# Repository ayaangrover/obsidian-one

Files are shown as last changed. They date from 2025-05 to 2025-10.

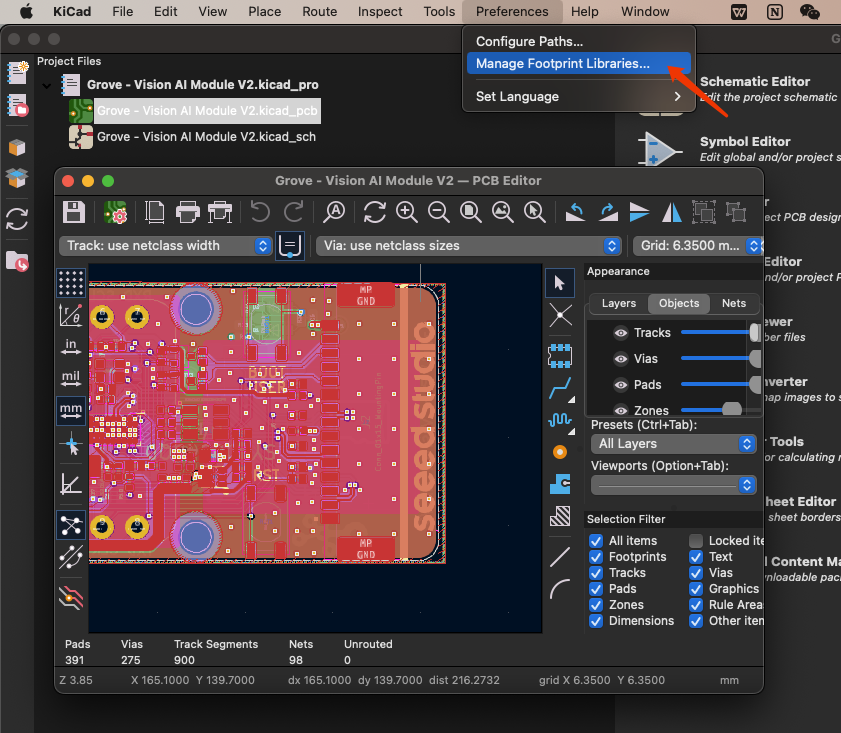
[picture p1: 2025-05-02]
pcb/OPL_Kicad_Library-master/images/4.png

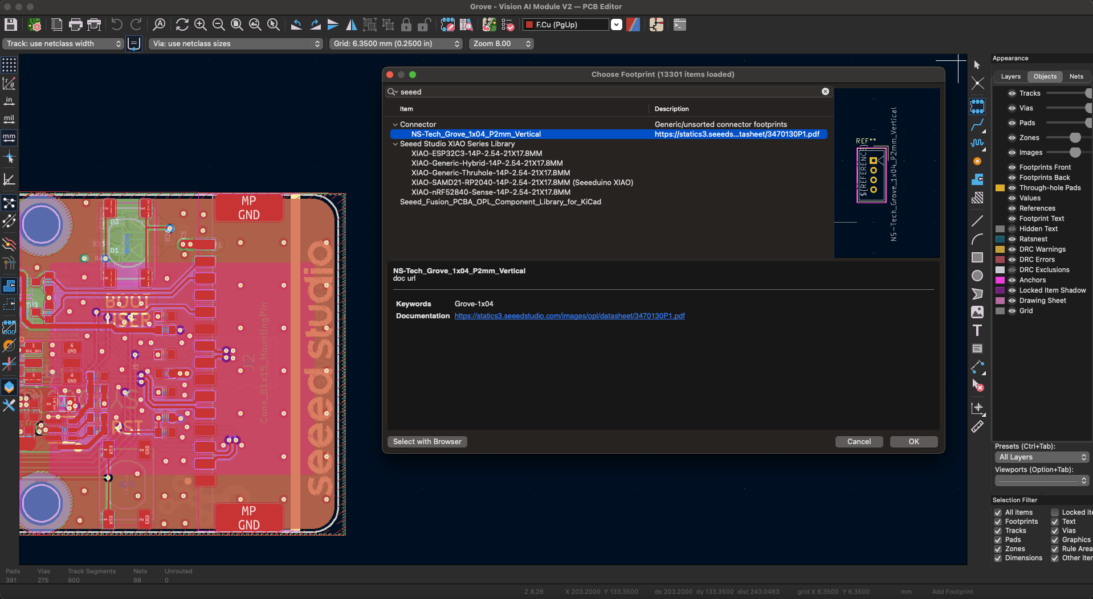
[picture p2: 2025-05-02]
pcb/OPL_Kicad_Library-master/images/19.png

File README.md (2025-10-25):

# Obsidian One: a 75% hotswappable mechanical keyboard

## Overview

The PCB uses MX-style switches with PCB mounting and hotswap. The MCU(microcontroller - the device that tells the computer whenever you press a key) is a basic [Pi Pico RP2040/RP2350](https://www.canakit.com/raspberry-pi-pico.html).

## Why I made it

My current keyboard(Keychron K6 from #pyramid-scheme) has no function key row, and requires an uncomfortable combo to pause music. To fix this, I made Obsidian One which has the extra row.

## PCB

The PCB is in the /keyboard folder. Inside is the production folder, which includes the gerber file.

## Firmware

### KMK

In the /firmware/kmk folder, you'll find a CIRCUITPY folder showing exactly what your MCU should look like when you plug it in. First, flash micropython. You can find instructions on how to do that [here](https://www.raspberrypi.com/documentation/microcontrollers/micropython.html). Then, eject, unplug, and reconnect the MCU. Once you're done, it should appear as a usb drive named CIRCUITPY. Now, replace the contents of the drive/mcu with the items in the /firmware/kmk/CIRCUITPY directory. Upon restarting(unplugging + reconnecting) the MCU, it should be functioning properly.

NOTE: This KMK firmware hasn't been tested. Flashing it to your microcontroller may cause damage or render it incapable of function. Use it at your own risk.

### QMK

The QMK firmware was made with QMK Configurator. It made a .hex file and I used microsoft's uf2conv.py and uf2families.json to convert it to a .uf2 file, which can be flashed to the MCU. You can see it at /firmware/qmk.

NOTE: This QMK firmware hasn't been tested. Flashing it to your microcontroller may cause damage or render it incapable of function. Use it at your own risk.

## Case

The case is available at ./case

## BOM

| Quantity | Item | Notes/Details | Source |
|---|---|---|---|
| 84x | Kailh Hotswap Sockets | | https://www.aliexpress.us/item/3256804104247622.html?gatewayAdapt=glo2usa |
| 84x | MX-compatible switches | MMD Princess Tactile 48gs | Amazon - https://www.amazon.com/KPREPUBLIC-Princess-Tactile-Mechanical-Keyboard/dp/B0C533FYXJ?sr=8-1 |
| 84x | Compatible keycaps | | [Amazon](https://www.amazon.com/dagaladoo-keycaps-Topographic-Percent-Keyboard/dp/B0CH2KSD7J?sr=8-68&xpid=GHBM-RxRzepH2) |
| 84x | 1N4148 THT Diodes | | https://www.aliexpress.us/item/2255800939822415.html?gatewayAdapt=glo2usa |
| 2x 2u, 1x 6.25u | Stabilizers | Cherry-style | [CannonKeys](https://cannonkeys.com/products/cherry-stabilizers?variant=32257338998895) |
| 1x | Orpheus Pico | Controller board | Hack Club HQ |
| 1x | Case | 3D-printed or purchased enclosure | JLCPCB/#printing-legion |
| 1x | PCB | Custom-designed for this project | JLCPCB |

### Extra stuff for the BOM:

- Solder

- Soldering Iron

- Flux as needed

## Pictures: 

CleanShot 2025-06-04 at 22 17 38

CleanShot 2025-05-09 at 12 09 41@2x

CleanShot 2025-05-09 at 12 36 32@2x

CleanShot 2025-05-09 at 12 40 01@2x

CleanShot 2025-10-25 at 07 35 13@2x

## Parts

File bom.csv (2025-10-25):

Quantity | Item | Notes/Details | Source
84x | Kailh Hotswap Sockets |  | https://www.aliexpress.us/item/3256804104247622.html?gatewayAdapt=glo2usa
84x | MX-compatible switches | MMD Princess Tactile 48gs | https://www.amazon.com/KPREPUBLIC-Princess-Tactile-Mechanical-Keyboard/dp/B0C533FYXJ?sr=8-1
84x | Compatible keycaps |  | https://www.amazon.com/Keycaps-Keyboard-Profile-Switches-Mechanical/dp/B0B4JV49DG?sr=8-22
84x | 1N4148 THT Diodes |  | https://www.aliexpress.us/item/2255800939822415.html?gatewayAdapt=glo2usa
2x 2u/1x 6.25u | Stabilizers |  | https://cannonkeys.com/products/cherry-stabilizers?variant=32257338998895
1x | Orpheus Pico / Pi Pico if Orpheus Pi isn't available | Preferrably an orph pico for usb c | Hack Club HQ
1x | Case |  | JLCPCB/#printing-legion
1x | PCB |  | JLCPCB

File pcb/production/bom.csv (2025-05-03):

Designator | Footprint | Quantity | Value | LCSC Part #
A1 | RaspberryPi_Pico_Common_THT | 1 | RaspberryPi_Pico
D1, D10, D11, D12, D13, D14, D15, D16, D17, D18, D19, D2, D20, D21, D22, D23, D24, D25, D26, D27, D28, D29, D3, D30, D31, D32, D33, D34, D35, D36, D37, D38, D39, D4, D40, D41, D42, D43, D44, D45, D46, D47, D48, D49, D5, D50, D51, D52, D53, D54, D55, D56, D57, D58, D59, D6, D60, D61, D62, D63, D64, D65, D66, D67, D68, D69, D7, D70, D71, D72, D73, D74, D75, D76, D77, D8, D82, D83, D84, D85, D86, D87, D88, D9 | Diode_DO-35 | 84 | Diode
S1, S10, S11, S12, S13, S14, S15, S16, S17, S18, S19, S2, S20, S21, S22, S23, S24, S25, S26, S27, S28, S29, S3, S32, S33, S34, S35, S36, S37, S38, S39, S4, S40, S41, S42, S43, S44, S46, S48, S49, S5, S50, S51, S52, S53, S54, S55, S56, S57, S58, S6, S61, S62, S63, S64, S65, S66, S67, S68, S69, S7, S70, S71, S73, S74, S8, S83, S84, S85, S86, S87, S88, S9 | Hotswap_MX_1.00u | 73 | Keyswitch
S30 | Hotswap_MX_2.00u | 1 | Keyswitch
S31, S45 | Hotswap_MX_1.50u | 2 | Keyswitch
S47, S72 | Hotswap_MX_1.75u | 2 | Keyswitch
S59, S60 | Hotswap_MX_2.25u | 2 | Keyswitch
S75, S76, S77 | Hotswap_MX_1.25u | 3 | Keyswitch
S82 | Hotswap_MX_6.25u | 1 | Keyswitch

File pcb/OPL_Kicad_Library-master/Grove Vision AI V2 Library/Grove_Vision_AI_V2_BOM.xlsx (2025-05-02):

Layer Jump | Number | Name | Specification | Operating Temperature | MPN Code | Quantity | Base | Plug Position | Process
N | 301010000 | SMD RES 0R-5%-1/16W;0402 |  | -55°C to 155°C | RC0402JR-070RL | 3 | 1 | R29,R30,R39 | SMT1
N | 301010004 | SMD RES 10K-5%-1/16W;0402 |  | -55°C to 155°C | RC0402JR-0710KL | 7 | 1 | R5,R7,R8,R23,R24,R31,R38 | SMT1
N | 301010008 | SMD RES 510K-5%-1/16W;0402 |  | -55°C to 155°C | RC0402JR-07510KL | 1 | 1 | R35 | SMT1
N | 301010456 | SMD RES 100K-1%-1/16W;0402 |  | -55°C to 155°C | RC0402FR-07100KL | 7 | 1 | R6,R10,R11,R16,R32,R33,R37 | SMT1
N | 301010495 | SMD RES;5.1K-1%-1/16W;0402 |  | -55°C to 155°C | RC0402FR-075K1L | 3 | 1 | R2,R3,R36 | SMT1
N | 301010746 | SMD RES 2.2K-1%-1/16W;0402 |  | -55°C to 155°C | RC0402FR-072K2L | 10 | 1 | R1,R4,R13,R14,R15,R19,R20,R21,R22,R40 | SMT1
N | 301011331 | SMD RES 22.1K-1%-1/16W;0402 |  | -55°C to 155°C | RC0402FR-0722K1L | 2 | 1 | R26,R34 | SMT1
N | 302010004 | SMD CAP Ceramic 100nF-16V-10%-X7R;0402 |  | -55°C to 125°C | CC0402KRX7R7BB104 | 18 | 1 | C5,C8,C13,C20,C21,C22,C23,C24,C25,C26,C27,C29,C30,C31,C32,C35,C36,C39 | SMT1
N | 302010006 | SMD CAP Ceramic 10nF-50V-10%-X7R;0402 |  | -55°C to 125°C | CC0402KRX7R9BB103 | 1 | 1 | C3 | SMT1
N | 302010049 | SMD CAP Ceramic 12pF-50V-5%-NPO;0402 |  | -55°C to 125°C | CC0402JRNPO9BN120 | 2 | 1 | C14,C15 | SMT1
N | 302010051 | SMD CAP Ceramic 220nF-16V-10%-X7R;0402 |  | -55°C to 125°C | CC0402KRX7R7BB224 | 1 | 1 | C16 | SMT1
N | 302010407 | SMD CAP Ceramic 4.7uF-10V-10%-X5R;0402 |  | -55°C to 85°C | CC0402KRX5R6BB475 | 7 | 1 | C4,C6,C7,C9,C10,C28,C34 | SMT1
N | 302010519 | SMD CAP Ceramic 10uF-10V-20%-X5R;0402 |  | -55°C to 85°C | CC0402MRX5R6BB106 | 2 | 1 | C11,C37 | SMT1
N | 302013249 | SMD CAP Ceramic 1uF-10V-10%-X5R;0402 |  | -55°C to 85°C | CL05A105KP5NNNC | 5 | 1 | C1,C2,C17,C18,C19 | SMT1
N | 303010544 | SMD Inductor 4.7uH-20%-1.1A;0806 |  | -40°C to 105°C | VLS201610HBX-4R7M-1 | 1 | 1 | L1 | SMT1
N | 303011858 | SMD Inductor 470nH-20%-2.6A;0603 |  | -40°C to 125°C | TFM160808ALC-R47MTAA | 2 | 1 | L2,L3 | SMT1
N | 304011053 | SMD Diode Schottky 40V-1A;SOD-323 |  |  | B5819WS SL | 4 | 1 | D1,D2,D3,D4 | SMT1
N | 304090121 | SMD LED Clear-Green;0402 | As posted |  | BL-HGE37A-AV-TRB | 1 | 1 | LED2 | SMT1
N | 304090746 | SMD LED Clear-Yellow;0402 | As posted |  | 16-213/Y2C-AN2Q1B/3T | 1 | 1 | LED1 | SMT1
N | 305030071 | SMD MOSFET N-CH 20V-500mA;SOT-523 |  |  | CJ1012 | 5 | 1 | Q1,Q2,Q3,Q4,Q5 | SMT1
N | 306011444 | SMD Crystal;24MHz-12pF-10ppm-4P-2.0*1.6*0.5mm |  | -40°C to 85°C | Y2400FE001 | 1 | 1 | X1 | SMT1
N | 310011697 | SMD IC MCU;Dual Cortex-M55 Core(Max 400MHz)-With a 400MHz NPU;WLCSP-65 | L5.58*W2.27mm | -40°C to 85°C | HX6538-A01TWA | 1 | 1 | U1 | SMT1
N | 310032794 | SMD IC PMIC;DCDC Buck-ADJ-2.2MHz-4A;DFN1.5×1.5-6 |  | -40°C to 85°C | SY80004DQD | 2 | 1 | U4,U6 | SMT1
N | 310032813 | SMD IC PMIC;LDO-1.8V-300mA;XTDFN-1*1-4L |  | -40°C to 125°C | SGM2036S-1.8XXDH4G/TR | 1 | 1 | U3 | SMT1
N | 310071431 | SMD IC Interface USB to High Speed TTL;QFN16 | USB to High-Speed Serial Port | -40°C to 85°C | CH343P | 1 | 1 | U2 | SMT1
N | 310091468 | SMD IC Memory;128Mbit-1.8V;SOIC-8 |  | -40°C to 85°C | W25Q128JWSIQ | 1 | 1 | U5 | SMT1
N | 311020009 | SMD Top Button 4N;4P-L4.6*W3.2*H2.5mm |  | -20°C to 70°C | SKRPADE010 | 1 | 1 | RST1 | SMT1
N | 311020518 | SMD Top Button 1.57N;4P-L4.6*W3.2*H2.5mm |  | -30°C to 85°C | SKRPABE010 | 1 | 1 | BOOT1 | SMT1
N | 312030502 | SMD DIGITAL MIC OMNI -26dBFS;OCLGA-4:3.5*2.65*0.94mm |  | -40˚C to 100˚C | MSM261D3526H1CPM | 1 | 1 | MIC1 | SMT1
N | 319015667 | PCB;Grove - Vision AI Module V2 -蓝油白字-4层 | 20*40*1.6mm-ENIG-FR4;Steel mesh code；404012305 |  |  | 1 | 1 |  | SMT1
N | 320011358 | SMD USB TYPE C-W/P;12+4P-8.94*7.35*3.26mm |  | -30°C to 85°C | USB-31C-F-16P-L7.35 | 1 | 1 | J1 | SMT1
N | 320031231 | DIP Black Female Header VERT;1*7P-2.54-5.0mm |  | -40℃ to 105℃ |  | 2 | 1 | P8,P9 | Unit
N | 320060904 | SMD FPC CONN Bottom Contact;15P-1.0mm;L19.9*W6.76*H2.0mm |  | -30°C to 85°C | ST-FPC-W102015-D | 1 | 1 | J2 | SMT1
N | 320090535 | SMD uSD Card Holder;9+4P-L11.25*W6.96*H1.42mm |  | -25°C to 70°C | ST-TF-MR267 | 1 | 1 | J5 | SMT1
N | 320110032 | SMD Grove Female Header-Beige;4P-2.0-90D | 2.0-4PHorizontal Mount with Locking Socket |  | PHS-4A horizontal mount | 1 | 1 | J3 | SMT1

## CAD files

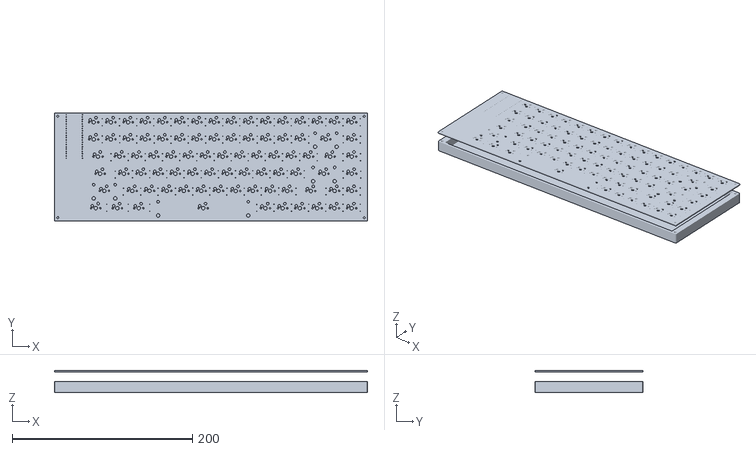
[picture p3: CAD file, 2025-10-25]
case/full.stl
347.0 x 119.7 x 24.5

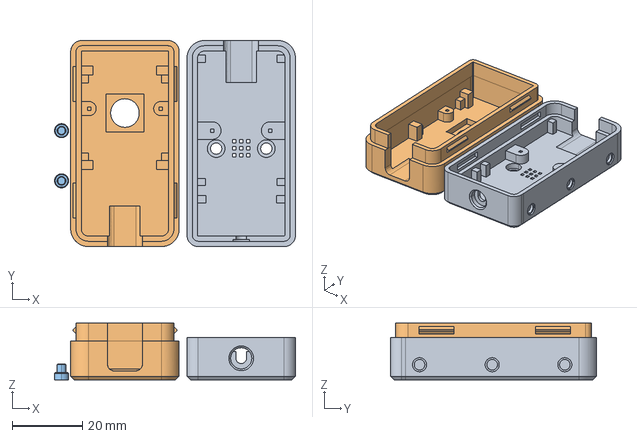
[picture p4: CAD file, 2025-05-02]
pcb/OPL_Kicad_Library-master/Grove Vision AI V2 Library/himax.stp
68.4 x 58.5 x 16.1 mm

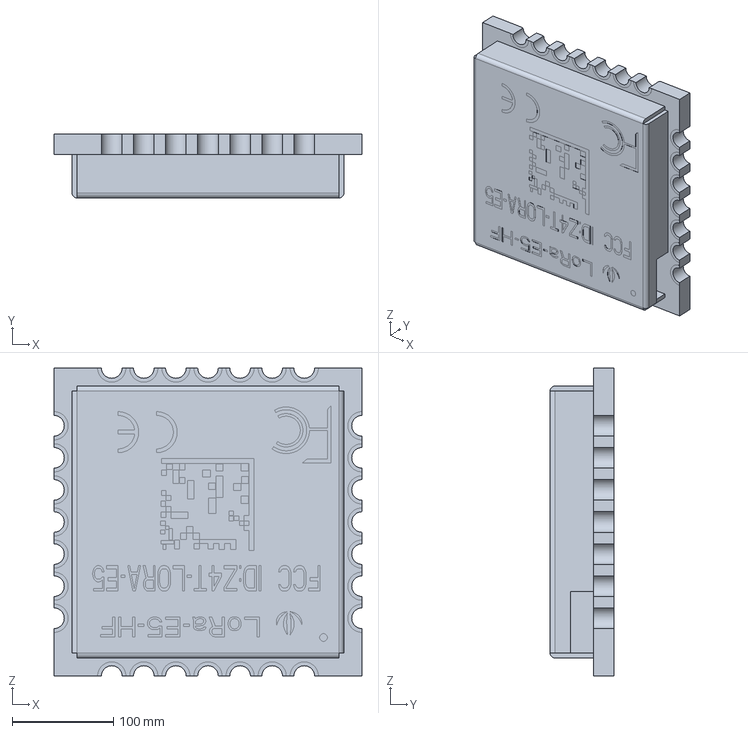
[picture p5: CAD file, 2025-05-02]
pcb/OPL_Kicad_Library-master/Seeed Studio Wio Series/Wio-E5-LE/LoRa-E5-LE-HF_3D_File.stp
304.8 x 63.8 x 304.8 mm

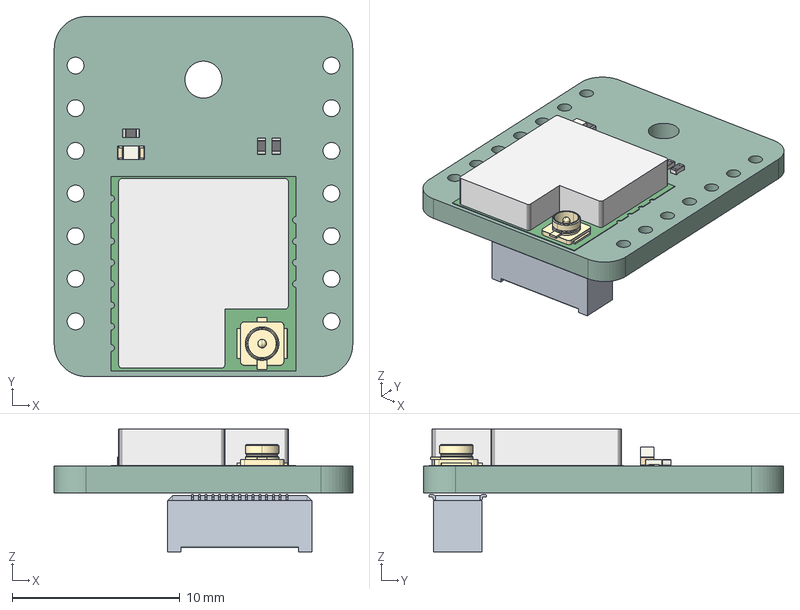
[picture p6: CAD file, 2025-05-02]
pcb/OPL_Kicad_Library-master/Seeed Studio Wio Series/Wio-SX1262/Wio-SX1262_for_XIAO_3D_file.step
17.8 x 21.4 x 7.30 mm
R_0402_1005Metric x 3
LED_0603_1608Metric
PCB
BF04-30pin-35H
Wio-SX1262 for XIAO V1.0_PCB

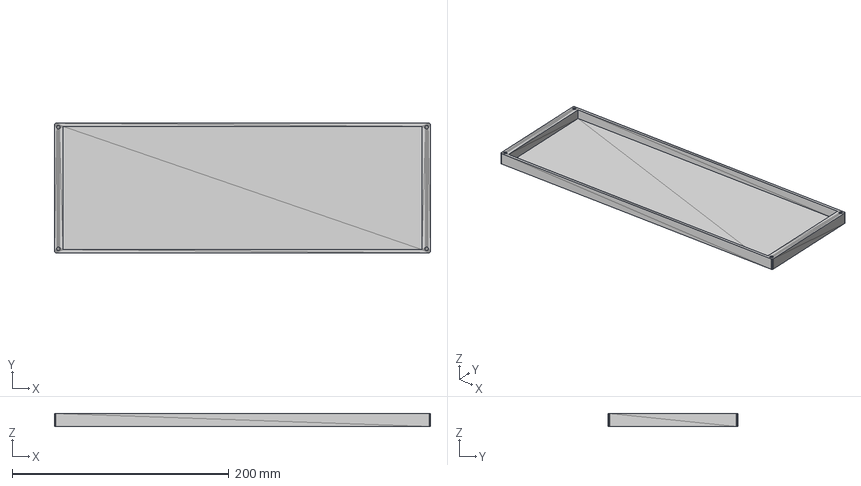
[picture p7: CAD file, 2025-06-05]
case/case.step
347.0 x 119.7 x 12.0 mm

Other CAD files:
case/case.stl
pcb/OPL_Kicad_Library-master/Grove Vision AI V2 Library/himax.3mf

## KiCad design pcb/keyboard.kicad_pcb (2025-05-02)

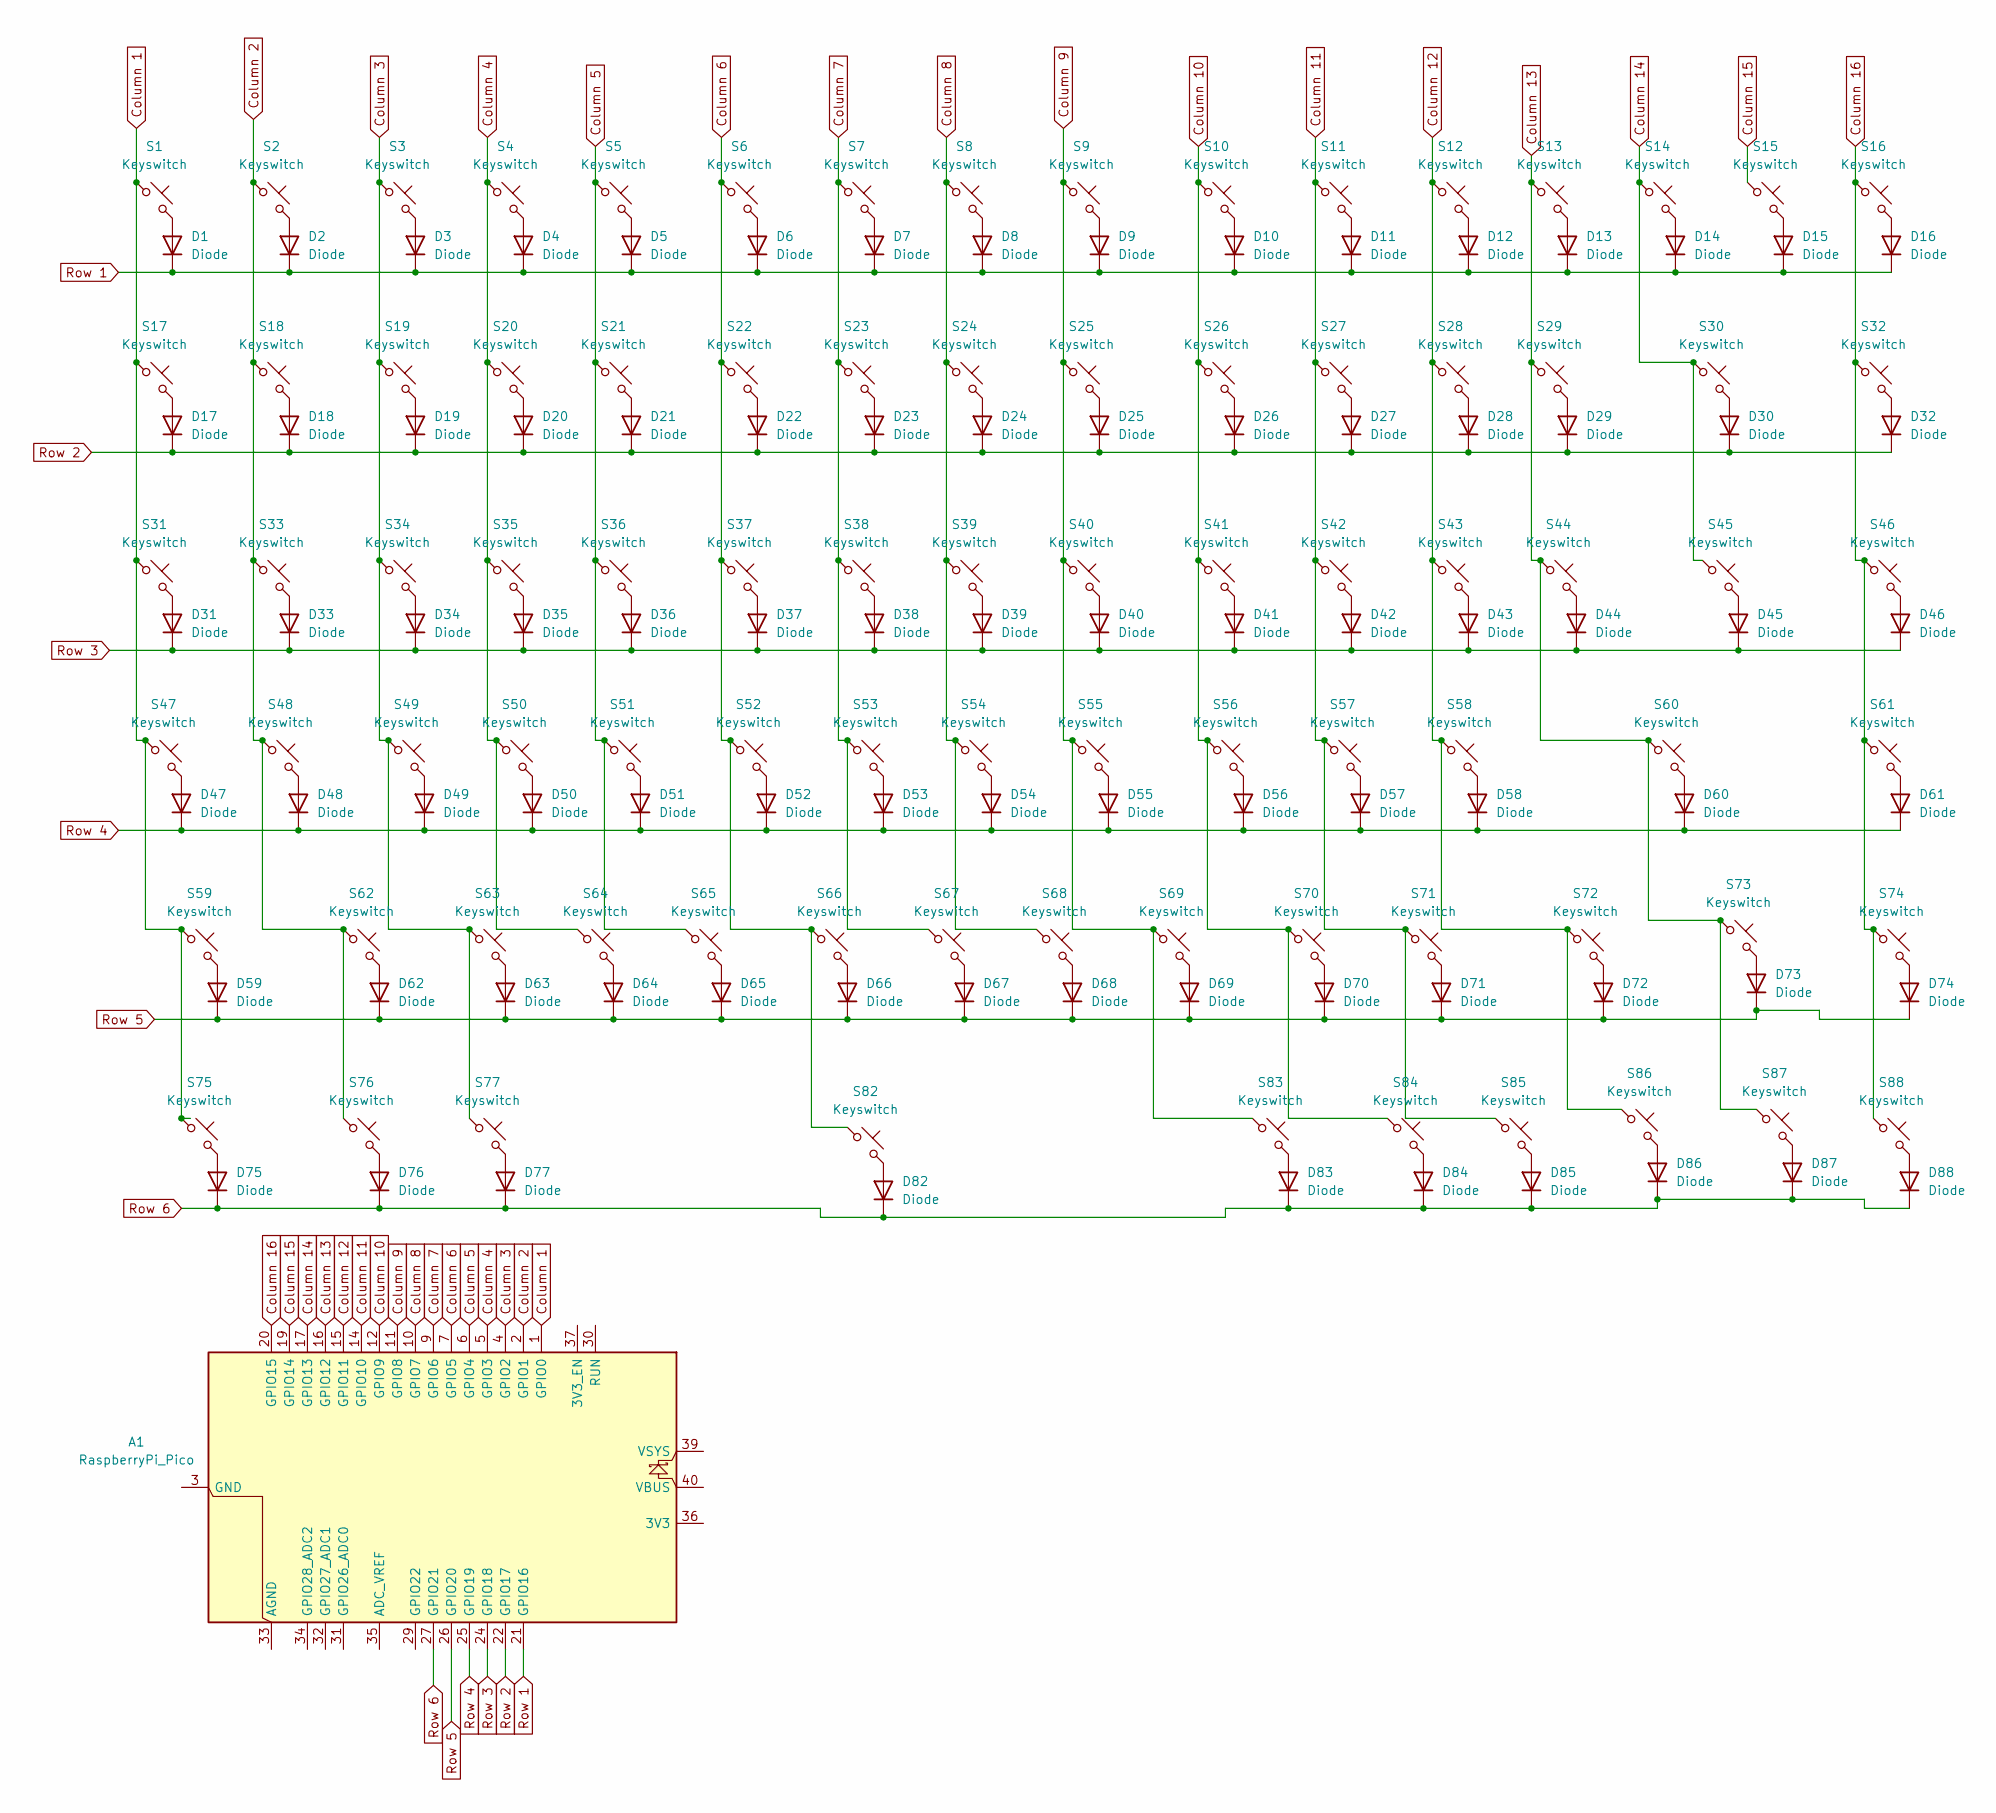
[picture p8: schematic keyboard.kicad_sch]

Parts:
A1: RaspberryPi_Pico; RaspberryPi_Pico_Common_THT
D1, D2, D3, D4, D5, D6, D7, D8, D9, D10, D11, D12, D13, D14, D15, D16, D17, D18, D19, D20, D21, D22, D23, D24, D25, D26, D27, D28, D29, D30, D31, D32, D33, D34, D35, D36, D37, D38, D39, D40, D41, D42, D43, D44, D45, D46, D47, D48, D49, D50, D51, D52, D53, D54, D55, D56, D57, D58, D59, D60, D61, D62, D63, D64, D65, D66, D67, D68, D69, D70, D71, D72, D73, D74, D75, D76, D77, D82, D83, D84, D85, D86, D87, D88: Diode; Diode_DO-35
S1, S2, S3, S4, S5, S6, S7, S8, S9, S10, S11, S12, S13, S14, S15, S16, S17, S18, S19, S20, S21, S22, S23, S24, S25, S26, S27, S28, S29, S32, S33, S34, S35, S36, S37, S38, S39, S40, S41, S42, S43, S44, S46, S48, S49, S50, S51, S52, S53, S54, S55, S56, S57, S58, S61, S62, S63, S64, S65, S66, S67, S68, S69, S70, S71, S73, S74, S83, S84, S85, S86, S87, S88: Keyswitch; Hotswap_MX_1.00u
S30: Keyswitch; Hotswap_MX_2.00u
S31, S45: Keyswitch; Hotswap_MX_1.50u
S47, S72: Keyswitch; Hotswap_MX_1.75u
S59, S60: Keyswitch; Hotswap_MX_2.25u
S75, S76, S77: Keyswitch; Hotswap_MX_1.25u
S82: Keyswitch; Hotswap_MX_6.25u

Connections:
Column 1: A1.1 (GPIO0), S1.1, S17.1, S31.1, S47.1, S59.1, S75.1
Column 2: A1.2 (GPIO1), S2.1, S18.1, S33.1, S48.1, S62.1, S76.1
Column 3: A1.4 (GPIO2), S3.1, S19.1, S34.1, S49.1, S63.1, S77.1
Column 4: A1.5 (GPIO3), S4.1, S20.1, S35.1, S50.1, S64.1
Column 5: A1.6 (GPIO4), S5.1, S21.1, S36.1, S51.1, S65.1
Column 6: A1.7 (GPIO5), S6.1, S22.1, S37.1, S52.1, S66.1, S82.1
Column 7: A1.9 (GPIO6), S7.1, S23.1, S38.1, S53.1, S67.1
Column 8: A1.10 (GPIO7), S8.1, S24.1, S39.1, S54.1, S68.1
Column 9: A1.11 (GPIO8), S9.1, S25.1, S40.1, S55.1, S69.1, S83.1
Column 10: A1.12 (GPIO9), S10.1, S26.1, S41.1, S56.1, S70.1, S84.1
Column 11: A1.14 (GPIO10), S11.1, S27.1, S42.1, S57.1, S71.1, S85.1
Column 12: A1.15 (GPIO11), S12.1, S28.1, S43.1, S58.1, S72.1, S86.1
Column 13: A1.16 (GPIO12), S13.1, S29.1, S44.1, S60.1, S73.1, S87.1
Column 14: A1.17 (GPIO13), S14.1, S30.1, S45.1
Column 15: A1.19 (GPIO14), S15.1
Column 16: A1.20 (GPIO15), S16.1, S32.1, S46.1, S61.1, S74.1, S88.1
unnamed: A1.3 (GND), A1.8 (GND), A1.13 (GND), A1.18 (GND), A1.23 (GND), A1.28 (GND), A1.38 (GND)
unnamed: D1.2 (A), S1.2
unnamed: D2.2 (A), S2.2
unnamed: D3.2 (A), S3.2
unnamed: D4.2 (A), S4.2
unnamed: D5.2 (A), S5.2
unnamed: D6.2 (A), S6.2
unnamed: D7.2 (A), S7.2
unnamed: D8.2 (A), S8.2
unnamed: D9.2 (A), S9.2
unnamed: D10.2 (A), S10.2
unnamed: D11.2 (A), S11.2
unnamed: D12.2 (A), S12.2
unnamed: D13.2 (A), S13.2
unnamed: D14.2 (A), S14.2
unnamed: D15.2 (A), S15.2
unnamed: D16.2 (A), S16.2
unnamed: D17.2 (A), S17.2
unnamed: D18.2 (A), S18.2
unnamed: D19.2 (A), S19.2
unnamed: D20.2 (A), S20.2
unnamed: D21.2 (A), S21.2
unnamed: D22.2 (A), S22.2
unnamed: D23.2 (A), S23.2
unnamed: D24.2 (A), S24.2
unnamed: D25.2 (A), S25.2
unnamed: D26.2 (A), S26.2
unnamed: D27.2 (A), S27.2
unnamed: D28.2 (A), S28.2
unnamed: D29.2 (A), S29.2
unnamed: D30.2 (A), S30.2
unnamed: D31.2 (A), S31.2
unnamed: D32.2 (A), S32.2
unnamed: D33.2 (A), S33.2
unnamed: D34.2 (A), S34.2
unnamed: D35.2 (A), S35.2
unnamed: D36.2 (A), S36.2
unnamed: D37.2 (A), S37.2
unnamed: D38.2 (A), S38.2
unnamed: D39.2 (A), S39.2
unnamed: D40.2 (A), S40.2
unnamed: D41.2 (A), S41.2
unnamed: D42.2 (A), S42.2
unnamed: D43.2 (A), S43.2
unnamed: D44.2 (A), S44.2
unnamed: D45.2 (A), S45.2
unnamed: D46.2 (A), S46.2
unnamed: D47.2 (A), S47.2
unnamed: D48.2 (A), S48.2
unnamed: D49.2 (A), S49.2
unnamed: D50.2 (A), S50.2
unnamed: D51.2 (A), S51.2
unnamed: D52.2 (A), S52.2
unnamed: D53.2 (A), S53.2
unnamed: D54.2 (A), S54.2
unnamed: D55.2 (A), S55.2
unnamed: D56.2 (A), S56.2
unnamed: D57.2 (A), S57.2
unnamed: D58.2 (A), S58.2
unnamed: D59.2 (A), S59.2
unnamed: D60.2 (A), S60.2
unnamed: D61.2 (A), S61.2
unnamed: D62.2 (A), S62.2
unnamed: D63.2 (A), S63.2
unnamed: D64.2 (A), S64.2
unnamed: D65.2 (A), S65.2
unnamed: D66.2 (A), S66.2
unnamed: D67.2 (A), S67.2
unnamed: D68.2 (A), S68.2
unnamed: D69.2 (A), S69.2
unnamed: D70.2 (A), S70.2
unnamed: D71.2 (A), S71.2
unnamed: D72.2 (A), S72.2
unnamed: D73.2 (A), S73.2
unnamed: D74.2 (A), S74.2
unnamed: D75.2 (A), S75.2
unnamed: D76.2 (A), S76.2
unnamed: D77.2 (A), S77.2
unnamed: D82.2 (A), S82.2
unnamed: D83.2 (A), S83.2
unnamed: D84.2 (A), S84.2
unnamed: D85.2 (A), S85.2
unnamed: D86.2 (A), S86.2
unnamed: D87.2 (A), S87.2
unnamed: D88.2 (A), S88.2
Row 1: A1.21 (GPIO16), D1.1 (K), D2.1 (K), D3.1 (K), D4.1 (K), D5.1 (K), D6.1 (K), D7.1 (K), D8.1 (K), D9.1 (K), D10.1 (K), D11.1 (K), D12.1 (K), D13.1 (K), D14.1 (K), D15.1 (K), D16.1 (K)
Row 2: A1.22 (GPIO17), D17.1 (K), D18.1 (K), D19.1 (K), D20.1 (K), D21.1 (K), D22.1 (K), D23.1 (K), D24.1 (K), D25.1 (K), D26.1 (K), D27.1 (K), D28.1 (K), D29.1 (K), D30.1 (K), D32.1 (K)
Row 3: A1.24 (GPIO18), D31.1 (K), D33.1 (K), D34.1 (K), D35.1 (K), D36.1 (K), D37.1 (K), D38.1 (K), D39.1 (K), D40.1 (K), D41.1 (K), D42.1 (K), D43.1 (K), D44.1 (K), D45.1 (K), D46.1 (K)
Row 4: A1.25 (GPIO19), D47.1 (K), D48.1 (K), D49.1 (K), D50.1 (K), D51.1 (K), D52.1 (K), D53.1 (K), D54.1 (K), D55.1 (K), D56.1 (K), D57.1 (K), D58.1 (K), D60.1 (K), D61.1 (K)
Row 5: A1.26 (GPIO20), D59.1 (K), D62.1 (K), D63.1 (K), D64.1 (K), D65.1 (K), D66.1 (K), D67.1 (K), D68.1 (K), D69.1 (K), D70.1 (K), D71.1 (K), D72.1 (K), D73.1 (K), D74.1 (K)
Row 6: A1.27 (GPIO21), D75.1 (K), D76.1 (K), D77.1 (K), D82.1 (K), D83.1 (K), D84.1 (K), D85.1 (K), D86.1 (K), D87.1 (K), D88.1 (K)

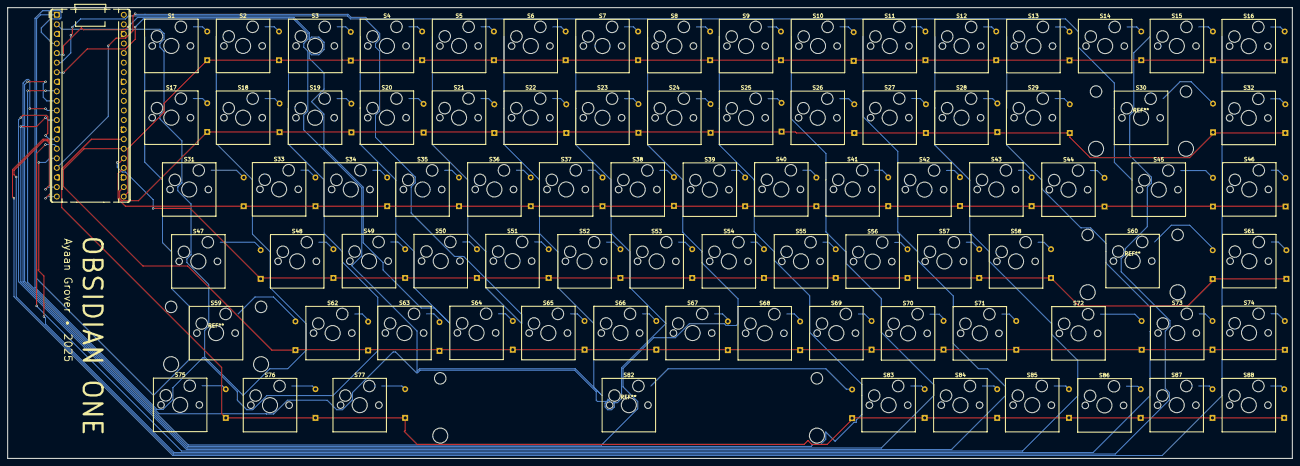
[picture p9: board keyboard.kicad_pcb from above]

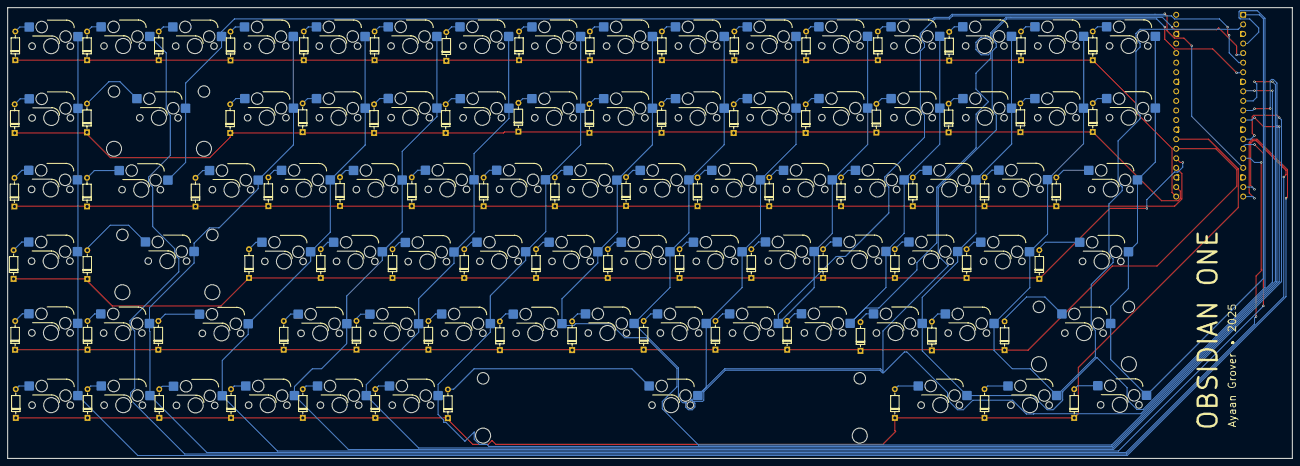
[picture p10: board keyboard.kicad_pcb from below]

Board: 2 copper layers, 341.1 x 119.7 mm, 169 parts (84 on the bottom side), 107 nets.

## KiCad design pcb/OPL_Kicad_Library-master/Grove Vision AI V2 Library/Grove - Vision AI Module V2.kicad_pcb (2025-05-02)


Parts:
BOOT1: SW_Push; SW_Push_1P1T_NO_Vertical_Wuerth_434133025816
C1, C2, C17, C18, C19: 1uF; C0402
C3: 10nF; C0402
C4, C6, C7, C9, C10, C28, C34: 4.7uF; C0402
C5, C8, C13, C20, C21, C22, C23, C24, C25, C26, C27, C29, C30, C31, C32, C35, C36, C39: 100nF; C0402
C11, C37: 10uF; C0402
C14, C15: 12pF; C0402
C16: 220nF; C0402
D1, D2, D3, D4: B5819WS; D0805_SOD323
D5, D6, D7, D8: DNP; R0402; MPN DF2S6.8FS
J1: USB_C_Receptacle_USB2.0; USB2.0-TYPE-C
J2: Conn_01x15_MountingPin; FPC_DNC_15P_1.0mm
J3: Conn_01x04_MountingPin; 4P-SMD-2.0mm-RIGHT
J5: ST-TF-MR267; SD-TF-MR267; MPN SD-TF-MR267
L1: VLS201610HBX-4R7M-1; L0806
L2, L3: 470nH; L0603
LED1: Yellow; LED0402
LED2: Green; LED0402
M1: XIAO Connector/DNP; XIAO_Socket
MIC1: MSM261D3526H1CPM; MIC6P-3.5X2.65X0.94MM
Q1, Q2, Q3, Q4, Q5: CJ1012; SOT523
R1, R4, R13, R14, R15, R19, R20, R21, R22, R40: 2.2k; R0402
R2, R3, R36: 5.1k; R0402
R5, R7, R23, R24: 10k; R0402
R6, R16, R32, R33: 100K; R0402; Power Rating 1%; MPN RC0402JR-074K7L
R8, R31, R38: 10K; R0402; Power Rating 5%; MPN RC0402JR-074K7L
R9, R12, R17, R18, R25, R27, R28: DNP; R0402
R10, R11, R37: 100k; R0402
R26, R34: 22K; R0402; Power Rating 1%; MPN RC0402JR-074K7L
R29, R30, R39: 0R; R0402
R35: 510k; R0402
RST1: SW_Push; SW_Push_1P1T_NO_Vertical_Wuerth_434133025816
TP1, TP2, TP3: Test Point; TP-D35MIL; Part Type Test Point
U1: HX6538; WLCSP65_5.6x2.3x0.56mm
U2: CH343P; QFN-16-EP_3x3mm_P0.5mm_EP1x1mm
U3: WR0331-18FF4R; X2SON-4
U4, U6: SY80004DQD; DFN6-0.5-1.5X1.5X0.65MM; MPN SY80004DQD
U5: W25Q128JWSIQ; SOIC-8_5.23x5.23mm_P1.27mm
X1: 24MHz; 4P2016

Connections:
1V8: C13.1, C19.2, C20.1, C21.1, C28.1, C29.2, Q1.1 (G), Q2.1 (G), R5.1, R21.2, R22.2, R25.1, TP2.1 (T), U1.F3 (VDDIO_SIF1), U1.G3 (VDDA_RX), U1.H5 (VDDA_TX), U1.L2 (VDDIO_SIF2), U3.1 (OUT), U5.8 (VCC)
/0V9: C4.1, C7.1, L1.2, U1.L4 (DCDC_OUT)
BOOTOPT0: D3.1 (K), R11.1, U1.F4 (BOOT_OPT)
GND: C1.2, C2.2, C3.2, C4.2, C5.2, C6.2, C7.2, C8.1, C9.2, C10.2, C11.1, C13.2, C14.2, C15.1, C17.2, C18.2, C19.1, C20.2, C21.2, C22.2, C23.2, C24.1, C25.1, C26.2, C27.1, C28.2, C29.1, C30.1, C31.2, C34.2, C35.1, C37.1, C39.1, D5.1, D6.1, D7.1, D8.1, J1.A1_B1_A12_B12 (GND), J1.S1 (SHIELD), J2.1, J2.4, J2.7, J2.10, J2.MP (MountPin), J3.4, J3.MP (MountPin), J5.S1 (SHD1), J5.S2 (SHD2), J5.S3 (SHD3), J5.S4 (SHD4), J5.T6 (VSS), LED2.1 (K), M1.13 (GND), MIC1.4 (GND), MIC1.5 (L/R), MIC1.6 (GND), Q3.2 (S), R2.2, R3.2, R10.2, R11.2, R23.2, R26.1, R34.1, R37.2, RST1.2, TP3.1 (T), U1.C5 (GND1), U1.G4 (GND2), U1.H3 (GND3), U1.L3 (GND4), U1.M2 (GND5), U1.M4 (GND6), U2.2 (GND), U2.17 (EPAD), U3.2 (GND), U3.T (GND), U4.4 (GND), U5.4 (GND), U6.4 (GND), X1.2 (1), X1.4 (3)
GROVE_5V_IN: C18.1, C34.1, C35.2, J3.3, R14.1, R15.1, R31.2, R32.2, U6.6 (IN)
I2CS0_SCL/5V: J3.1, Q4.3 (D), R14.2
I2CS0_SDA/5V: J3.2, Q5.3 (D), R15.2
M_3V3_SCL: J2.13, Q1.3 (D), R19.2
M_3V3_SDA: J2.14, Q2.3 (D), R20.2
unnamed: BOOT1.2, R4.2
unnamed: D1.2 (A), R36.2
unnamed: C9.1, C10.1, C27.2, D2.1 (K), D4.1 (K), R6.2, R8.2, U4.6 (IN)
unnamed: BOOT1.1, D3.2 (A), R36.1
unnamed: J1.A5 (CC1), R2.1
unnamed: J1.B5 (CC2), R3.1
unnamed: LED1.2 (A), R38.1
unnamed: LED1.1 (K), Q3.3 (D)
unnamed: LED2.2 (A), R24.2
unnamed: M1.12 (3V3), R39.2
unnamed: MIC1.2 (CLK), R29.1
unnamed: MIC1.3 (DATA), R30.1
unnamed: Q3.1 (G), R37.1, R40.2
unnamed: R10.1, U1.E4 (TEST_MODE)
unnamed: L1.1, U1.L5 (VX1)
unnamed: C14.1, R35.1, U1.G2 (XTAL_24M_I), X1.3 (4)
unnamed: C15.2, R35.2, U1.F1 (XTAL_24M_O), X1.1 (2)
unnamed: C16.2, U2.13 (RTS)
unnamed: R8.1, U4.1 (EN)
unnamed: C32.1, R16.1, R26.2, U4.3 (FB)
unnamed: L2.1, U4.5 (LX)
unnamed: R6.1, U4.2 (PG)
unnamed: R31.1, U6.1 (EN)
unnamed: C36.1, R33.1, R34.2, U6.3 (FB)
unnamed: L3.1, U6.5 (LX)
unnamed: R32.1, U6.2 (PG)
PA0/3V3: M1.1 (D0/A0), U1.D4 (PA0)
PA1/VMUTE/3V3: J2.11, U1.C4 (PA1)
PA2/I2CS0_SCL/3V3: M1.6 (D5/SCL), Q4.2 (S), R1.1, R17.2, U1.A4 (PA2)
PA3/I2CS0_SDA/3V3: M1.5 (D4/SDA), Q5.2 (S), R13.1, R18.2, U1.B4 (PA3)
PB0/RX0/3V3: U1.A5 (PB0), U2.4 (TXD)
PB1/TX0/3V3: U1.B5 (PB1), U2.5 (RXD)
PB2/SSPIM_DO/3V3: D7.2, J5.T3 (CMD), M1.11 (D10/MOSI), R12.2, U1.N5 (PB2)
PB3/SSPIM_DI/3V3: D5.2, J5.T7 (DAT0), M1.10 (D9/MISO), R9.2, U1.M3 (PB3)
PB4/SSPIM_SCLK/3V3: D6.2, J5.T5 (CLOCK), M1.9 (D8/SCK), R27.2, U1.N4 (PB4)
PB5/SSPIM_~CS/3V3: D8.2, J5.T2 (CD/DAT3), R28.2, U1.N3 (PB5)
PB6/UART1_RX/3V3: M1.7 (D6/TX), U1.N1 (PB6)
PB7/UART1_TX/3V3: M1.8 (D7/RX/SS), U1.M1 (PB7)
PB8/3V3: M1.3 (D2/A2), U1.L1 (PB8)
PB9/PDM_CLK/3V3: R29.2, U1.F5 (PB9)
PB10/PDM_DATA0/3V3: R30.2, U1.G5 (PB10)
PB11/3V3: M1.2 (D1/A1), U1.J3 (PB11)
QSPI_CLK: U1.C2 (QSPI_CLK), U5.6 (CLK)
QSPI_CS: R5.2, U1.B2 (QSPI_CS), U5.1 (~CS)
QSPI_D0: U1.B1 (QSPI_DIO0), U5.5 (DI(IO0))
QSPI_D1: U1.D3 (QSPI_DIO1), U5.2 (DO(IO1))
QSPI_D2: U1.A1 (QSPI_DIO2), U5.3 (IO2)
QSPI_D3: U1.E3 (QSPI_DIO3), U5.7 (IO3)
RST: C3.1, C16.1, M1.4 (D3/A3), R7.1, RST1.1, U1.E5 (RESETN)
RX_CK_N: J2.8, U1.E2 (RX_CKN)
RX_CK_P: J2.9, U1.F2 (RX_CKP)
RX_D0_N: J2.2, U1.D2 (RX_DN0)
RX_D0_P: J2.3, U1.C1 (RX_DP0)
RX_D1_N: J2.5, U1.D1 (RX_DN1)
RX_D1_P: J2.6, U1.E1 (RX_DP1)
SEN_D1/SD~INSERT: J5.G1 (SWITCH), R25.2, U1.G1 (SEN_D1)
SEN_I2CM_SCL: Q1.2 (S), R21.1, U1.A3 (SEN_I2CM_SCL)
SEN_I2CM_SDA: Q2.2 (S), R22.1, U1.B3 (SEN_I2CM_SDA)
UD+: J1.A6 (D+), J1.B6 (D+), U2.7 (D+)
UD-: J1.A7 (D-), J1.B7 (D-), U2.8 (D-)
USER_LED/1V8: R40.1, U1.K2 (SEN_D2)
USR_BTN/1V8: D1.1 (K), R23.1, U1.H1 (SEN_D0)
V33IO: C2.1, C31.1, U2.1 (VIO), U2.6 (V3)
VBUS: C1.1, C30.2, D4.2 (A), J1.A4_B4_A9_B9 (VBUS), U2.3 (VDD5), U2.9 (VBUS)
VCC_3V3: C5.1, C6.1, C8.2, C11.2, C17.1, C22.1, C23.1, C24.2, C25.2, C26.1, C32.2, C36.2, C37.2, C39.2, J2.15, J5.T4 (VDD), L2.2, L3.2, MIC1.1 (VDD), Q4.1 (G), Q5.1 (G), R1.2, R4.1, R7.2, R9.1, R12.1, R13.2, R16.2, R17.1, R18.1, R19.1, R20.1, R24.1, R27.1, R28.1, R33.2, R38.2, R39.1, TP1.1 (T), U1.D5 (VDDIO_AON), U1.M5 (VDDA_DCDC), U1.N2 (VDDIO_PIF), U3.3 (EN), U3.4 (IN)
VMAIN: D2.2 (A), M1.14 (VUSB)

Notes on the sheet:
MIPI CSI
AON 3V3
MIPI DSI
PIF 3V3
SIF only 1V8
Imax=600mA
23/11/14
Grove - Vision AI Module V2
JN.FUONG



Board: 4 copper layers, 40.0 x 20.0 mm, 112 parts (31 on the bottom side), 75 nets.

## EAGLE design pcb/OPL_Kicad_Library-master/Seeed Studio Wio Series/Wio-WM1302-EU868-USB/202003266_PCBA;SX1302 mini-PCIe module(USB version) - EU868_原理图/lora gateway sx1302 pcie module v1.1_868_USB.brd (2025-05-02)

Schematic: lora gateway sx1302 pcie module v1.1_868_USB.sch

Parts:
ANT1: U.FL-R-SMT-1(10); U-FL3P-SMD-2.6X2.6X1.0MM
ANT2: DNP; U-FL3P-SMD-2.6X2.6X1.0MM
C1, C12, C15, C19, C23, C25, C26, C29, C32, C41, C43, C45, C65, C67, C80, C83, C86, C88: 100nF; C0402
C2, C75: 2.2pF; C0402
C3, C92: 10uF; C0603
C4, C8, C11, C16, C17, C18, C64: 56pF; C0402
C5, C6, C9, C10: 3.6pF; C0402
C7, C91: 5.6pF; C0402
C13, C20, C21, C24, C28, C35, C39, C40, C42, C44, C47, C48, C76, C87, C89: 1uF; C0402
C14, C38, C57, C66, C81, C84: 10pF; C0402
C22, C27, C33: 10uF; C0603@1
C30, C56, C74, C77, C78, C79: DNP; C0402
C31: DNP; C0603@1
C34, C46, C63: 470nF; C0402
C36: 47nF; C0402
C37: 47pF; C0402
C49: 4.7uF; C0603
C50, C62, C85: 10nF; C0402
C51: 1nF; C0402
C52, C55: 100pF; C0402
C53, C60, C61: 3.3pF; C0402
C54: 39pF; C0402
C58: 1.3pF; C0402
C59, C68, C73: 1.8pF; C0402
C69, C70, C71, C72: 10uF; C0805
C82: 2.7pF; C0402
C90: 2.2uF; C0603
D1, D4: Green; LED-0402
D2: Red; LED-0402
D3: Blue; LED-0402
D5: LXES15AAA1-153; ESD-0402
D6: DNP; ESD-0402
D7: BAT54XV2T1G; SOD-523
FB1: BLM15PD121SN1D; F0402
J1: DNP; PCIE52P-0.8-50.95X30MM
L1: LQP15MN1N2B02D; L0402
L2: LQW15AN6N8G00D; L0402
L4: 0R; F0603
L5: LQH44PN1R0NP0L; L4.4X3.0MM
L6, L14, L20: MLZ2012M150WT; L0805
L7, L15, L18, L21: DNP; L0402
L8: LQW15AN3N0B00; L0402
L9: LQW15AN47NJ00D; L0402
L10: LQW15AN2N5B00D; L0402
L11: LQW15AN4N7C00D; L0402
L12, L13: LQW15AN12NG00D; L0402
L16: LQW15AN7N5G00D; L0402
L17, L24: LQW15AN5N6C10D; L0402
L22: LQW15AN15NG00D; L0402
Q8: CJ2101; SOT-323
Q10: CJ2102; SOT-323
R1, R4, R33, R34, R38, R42, R57, R65, R71: 10k; R0402
R2, R7: 0R; R0603
R3, R8, R11, R12, R43, R44, R46, R49, R51, R55, R56, R59, R60, R61, R62, R63, R67, R70, R72, R73, R74, R75, R76, R81: DNP; R0402
R5, R10, R14, R15, R16, R39, R40, R41: 100R; R0402
R6, R9, R37: 220R; R0402
R13, R35, R52: DNP; R0603
R17, R18, R19, R20, R21, R22, R23, R24, R25, R26, R27, R28, R29, R36, R45, R48, R50, R53, R54, R69, R77: 0R; R0402
R30, R31, R32: 680R; R0402
R47, R79: 1k; R0402
R58, R68: 4.7k; R0402
R64, R66: 22R; R0402
R78, R82: 100k; R0402
R80: 10R; R0402
R83, R87: 200k_1%; R0402
S1, S2, S3, S4, S5, S6: 323030226; SHIELD_CLIP
TP1, TP2, TP3, TP4, TP5, TP6, TP7, TP8, TP9, TP10, TP14: TEST-POINT-35; TP_3535
TP15: TEST-POINT'4545'; TP-D45MIL
U1: SX1302IMLTRT; QFN68-0.35-7X7X0.75MM
U2, U8, U10: HDF866A3-S6; FILTER6P-1.1-3X3X1.3MM
U3, U4: DNP; SOT-23-5
U5, U7: SX1250IMLTRT; QFN24G-0.5-4X4MM
U6: MP2161GJ; TSOT23-8
U9: SKY66420-11; MODULE16P-0.5-3X3X0.75MM
U11: SX1262IMLTRT; QFN24G-0.5-4X4MM
U12: STM32L412K8U6; UFQFPN32-0.5-5X5MM
U13: STTS751; UDFN-6L
X1: DSB221SDN; X4-SMD-2.5X2.0X1.0MM
X3: 32.768kHz; X2-SMD-3.2X1.5X0.55MM

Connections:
32MHZ: R6.2, R9.2, R37.2, X1.3 (OUT)
1302_CS: R33.2, R43.1, U1.1 (HOST_CSN), U12.10 (PA4)
1302_RESET: C1.2, D7.-, R1.2, U1.7 (RESET), U12.8 (PA2)
1302_RESET_HOST: D7.+, R59.1
CONFIG_OK: R31.1, U1.66 (GPIO0)
DM: J1.36, R66.1
DP: J1.38, R64.1
FEM_CS: R14.2, R34.1, U1.10 (RADIO_CTRL0), U3.3 (CE)
FEM_PA_ON: R15.2, U1.16 (RADIO_CTRL4)
GND: ANT1.GND1, ANT1.GND2, ANT2.GND1, ANT2.GND2, C2.1, C3.1, C5.1, C7.1, C9.1, C12.1, C13.1, C15.1, C16.1, C17.1, C18.1, C19.1, C20.1, C21.1, C22.1, C23.1, C24.1, C25.1, C26.1, C27.1, C28.1, C29.1, C30.1, C31.1, C32.1, C33.1, C34.1, C35.1, C36.1, C37.1, C39.1, C40.1, C41.1, C42.1, C43.1, C44.1, C45.1, C46.1, C47.1, C48.1, C49.1, C50.1, C51.1, C52.1, C55.1, C56.1, C57.1, C58.1, C60.2, C61.2, C62.1, C63.2, C65.2, C67.2, C69.1, C70.1, C71.1, C72.1, C73.2, C74.2, C76.1, C77.2, C78.2, C80.1, C81.2, C82.2, C83.1, C84.2, C85.1, C86.1, C87.1, C88.1, C89.1, C90.1, C92.1, D1.-, D2.-, D3.-, D4.-, D5.1, D6.1, J1.4 (GND), J1.9 (GND), J1.15 (GND), J1.18 (GND), J1.21 (GND), J1.26 (GND), J1.27 (GND), J1.29 (GND), J1.34 (GND), J1.35 (GND), J1.37 (GND), J1.40 (GND), J1.43 (GND), J1.50 (GND), J1.S1 (GND), J1.S2 (GND), Q10.2 (S), R1.1, R4.1, R11.1, R12.1, R17.2, R53.1, R53.2, R54.1, R54.2, R55.1, R55.2, R57.2, R73.1, R74.1, R74.2, R87.1, S1.S1, S1.S2, S1.S3, S1.S4, S1.S5, S2.S1, S2.S2, S2.S3, S2.S4, S2.S5, S3.S1, S3.S2, S3.S3, S3.S4, S3.S5, S4.S1, S4.S2, S4.S3, S4.S4, S4.S5, S5.S1, S5.S2, S5.S3, S5.S4, S5.S5, S6.S1, S6.S2, S6.S3, S6.S4, S6.S5, TP3.T, U1.6 (GND), U1.9 (GND), U1.15 (GND), U1.24 (GND), U1.25 (GND), U1.39 (GND), U1.46 (GND), U1.55 (GND), U1.62 (GND), U1.69 (GND), U2.1 (GND), U2.3 (GND), U2.4 (GND), U2.6 (GND), U3.2 (VSS), U4.2 (VSS), U5.7 (GND), U5.20 (GND), U5.PAD, U6.4 (PGND), U6.6 (AGND), U7.7 (GND), U7.20 (GND), U7.PAD, U8.1 (GND), U8.3 (GND), U8.4 (GND), U8.6 (GND), U9.10 (GND), U9.12 (GND), U9.17 (EPAD), U10.1 (GND), U10.3 (GND), U10.4 (GND), U10.6 (GND), U11.2 (GND), U11.5 (GND), U11.8 (GND), U11.20 (GND), U11.PAD, U12.16 (VSS), U12.32 (VSS), U12.PAD, U13.4 (ADDR/!THERM), U13.5 (GND), X1.2 (GND)
HOST_CS0: J1.51, R43.2
HOST_CS1: J1.25, R51.2
HOST_IO1: J1.33, R61.2
HOST_IO2: J1.31, R63.2
HOST_IO3: J1.23
HOST_IO4: J1.8, R67.2
HOST_IO5: J1.10, R60.2
HOST_IO6: J1.12
HOST_MISO: R39.1, R44.2
HOST_MOSI: J1.49, R46.2
HOST_RST: J1.22, R59.2, R77.2
HOST_SCK: J1.45, R49.2
I2C_SCL: R68.2, R76.1, R81.1, U12.29 (PB6), U13.1 (SCL)
I2C_SDA: R58.2, R70.1, R75.1, U12.30 (PB7), U13.6 (SDA)
MCU_RESET: C85.2, R71.2, R77.1, TP5.T, U12.4 (NRST)
MISO: R44.1, R45.1, U1.2 (HOST_MISO), U11.16 (MISO)
MISO_A: U1.42 (RADIO_A_MISO), U5.16 (MISO)
MISO_B: U1.33 (RADIO_B_MISO), U7.16 (MISO)
MOSI: R5.2, R40.2, R46.1, R48.1
MOSI_A: U1.67 (RADIO_A_MOSI), U5.17 (MOSI)
MOSI_B: U1.19 (RADIO_B_MOSI), U7.17 (MOSI)
unnamed: C11.2, U9.2 (RX)
unnamed: TP15.T, U6.1 (PG)
unnamed: C8.1, R11.2, R52.2, U8.5 (OUT)
unnamed: C2.2, L11.2, R52.1, U8.2 (IN)
unnamed: C11.1, R13.2, U2.2 (IN)
unnamed: C4.2, U9.1 (TX)
unnamed: C68.1, C74.1, C75.2
unnamed: C65.1, L18.2, R36.2, U11.1 (VDD_IN)
unnamed: C66.2, R37.1
unnamed: L5.1, U6.3 (SW)
unnamed: R83.1, R87.2, U6.7 (FB)
unnamed: R3.1, R4.2, X1.1 (ENABLE)
unnamed: C14.1, U5.3 (XTA)
unnamed: C62.2, L4.1, R3.2, X1.4 (VDD)
unnamed: R5.1, U1.3 (HOST_MOSI)
unnamed: D4.+, R47.2
unnamed: R10.1, U1.4 (HOST_SCK)
unnamed: R82.2, U6.8 (EN)
unnamed: R8.1, U4.3 (CE)
unnamed: C14.2, R6.1
unnamed: L6.2, U5.8 (DCC_SW)
unnamed: C34.2, L6.1, L7.2, U5.6 (VREG)
unnamed: C64.1, C82.1, L24.2
unnamed: R19.1, U1.34 (RADIO_B_CLK_I)
unnamed: C16.2, R14.1, U9.4 (CSD)
unnamed: C38.1, U7.3 (XTA)
unnamed: C36.2, C37.2, L9.2, U5.1 (VR_PA)
unnamed: C38.2, R9.1
unnamed: L14.2, U7.8 (DCC_SW)
unnamed: C46.2, L14.1, L15.2, U7.6 (VREG)
unnamed: C54.2, L11.1
unnamed: C7.2, C53.2, C54.1, L10.2
unnamed: C4.1, C8.2, R12.2
unnamed: C17.2, R15.1, U9.5 (CPS)
unnamed: C18.2, R16.1, U9.6 (CTX)
unnamed: R17.1, U1.20 (SP_VALID)
unnamed: R18.1, U1.32 (RADIO_B_IQ3)
unnamed: R20.1, U1.35 (RADIO_B_IQ0)
unnamed: R24.1, U1.41 (RADIO_A_IQ3)
unnamed: R21.1, U1.36 (RADIO_B_IQ1)
unnamed: R22.1, U1.37 (RADIO_B_IQ4)
unnamed: R23.1, U1.38 (RADIO_B_IQ2)
unnamed: R25.1, U1.43 (RADIO_A_CLK_I)
unnamed: R26.1, U1.44 (RADIO_A_IQ0)
unnamed: R27.1, U1.45 (RADIO_A_IQ1)
unnamed: R28.1, U1.48 (RADIO_A_IQ4)
unnamed: R29.1, U1.49 (RADIO_A_IQ2)
unnamed: D3.+, R32.2
unnamed: D2.+, R31.2
unnamed: D1.+, R30.2
unnamed: Q8.1 (G), Q10.3 (D), R78.2
unnamed: C1.1, R80.1
unnamed: L1.1, U9.16 (VCC1)
unnamed: L2.1, L8.1, U9.13 (PA_OUT)
unnamed: C56.2, C57.2, L8.2, L16.1
unnamed: C58.2, L16.2, U9.11 (TX_IN)
unnamed: C59.2, C60.1, L17.1, U9.9 (ANT)
unnamed: C61.1, C91.1, L17.2, L24.1
unnamed: C66.1, U11.3 (XTA)
unnamed: ANT1.D, C64.2, D5.2
unnamed: R35.2, R62.1, R69.2, U10.2 (IN)
unnamed: C63.1, L18.1, L20.1, U11.7 (VREG)
unnamed: R35.1, U9.7 (LNA_IN), U10.5 (OUT)
unnamed: L20.2, U11.9 (DCC_SW)
unnamed: J1.47, R39.2
unnamed: R40.1, U11.17 (MOSI)
unnamed: R41.1, U11.18 (SCK)
unnamed: C6.1, C10.1, C75.1, R13.1, U2.5 (OUT)
unnamed: R69.1, U9.8 (RX_FLT)
unnamed: C78.1, C79.1, L21.2
unnamed: ANT2.D, C79.2, D6.2
unnamed: C59.1, C91.2
unnamed: C77.1, L21.1, R62.2
unnamed: R65.2, U13.2 (!EVENT)
unnamed: C52.2, FB1.1, L1.2, U9.15 (VCC0)
unnamed: R64.2, U12.22 (PA12)
unnamed: R66.2, U12.21 (PA11)
unnamed: C92.2, Q10.1 (G), R79.2
unnamed: R56.2, R57.1, U12.31 (BOOT0)
unnamed: R72.2, R73.2, U12.6 (PA0-CLK_IN)
unnamed: C81.1, U12.2 (PC14-OSC32_IN), X3.2
unnamed: C84.1, U12.3 (PC15-OSC32_OUT), X3.1
unnamed: J1.14, R76.2
unnamed: J1.16, R70.2
unnamed: J1.30, R81.2
unnamed: J1.32, R75.2
PPS: J1.19, TP2.T, U1.8 (PPS), U12.27 (PB4)
RADIO_A_CLK_32M: R25.2, R72.1, U5.14 (BUSY)
RADIO_A_CLK_O: R28.2, U5.11 (DIO5)
RADIO_A_CSN: U1.68 (RADIO_A_CSN), U5.19 (NSS)
RADIO_A_IQ_0: R26.2, U5.13 (DIO1)
RADIO_A_IQ_1: R27.2, U5.12 (DIO2)
RADIO_A_IQ_2: R29.2, U5.5 (DIO3)
RADIO_A_IQ_3: R24.2, U5.21 (DIO4)
RADIO_A_RESET: U1.13 (RADIO_CTRL3), U5.15 (NRESET)
RADIO_A_RFIN: C6.2, L12.2, U5.23 (RFI_N)
RADIO_A_RFIP: C5.2, L12.1, U5.22 (RFI_P)
RADIO_B_CLK_32M: R19.2, U7.14 (BUSY)
RADIO_B_CLK_O: R22.2, U7.11 (DIO5)
RADIO_B_CSN: U1.18 (RADIO_B_CSN), U7.19 (NSS)
RADIO_B_IQ0: R20.2, U7.13 (DIO1)
RADIO_B_IQ_1: R21.2, U7.12 (DIO2)
RADIO_B_IQ_2: R23.2, U7.5 (DIO3)
RADIO_B_IQ_3: R18.2, U7.21 (DIO4)
RADIO_B_RESET: U1.28 (RADIO_CTRL9), U7.15 (NRESET)
RADIO_B_RFIN: C10.2, L13.2, U7.23 (RFI_N)
RADIO_B_RFIP: C9.2, L13.1, U7.22 (RFI_P)
RFO: C53.1, L9.1, L10.1, U5.24 (RFO)
RX_ON: R32.1, U1.59 (GPIO4)
SCK: R10.2, R41.2, R49.1, R50.1
SCK_A: U1.65 (RADIO_A_SCK), U5.18 (SCK)
SCK_B: U1.21 (RADIO_B_SCK), U7.18 (SCK)
STM32_MISO: R45.2, U12.12 (PA6)
STM32_MOSI: R48.2, U12.13 (PA7)
STM32_SCK: R50.2, U12.11 (PA5)
SWCLK: TP7.T, U12.24 (PA14)
SWDIO: TP8.T, U12.23 (PA13)
SX1261_BUSY: R67.1, U11.14 (BUSY), U12.9 (PA3)
SX1261_CS: R42.1, R51.1, U11.19 (NSS), U12.14 (PB0)
SX1261_IO1: R61.1, U1.54 (GPIO7), U11.13 (DIO1), U12.15 (PB1)
SX1261_IO2: R63.1, U11.12 (DIO2)
SX1261_IO3: TP9.T, U11.6 (DIO3)
SX1261_RFIN: C68.2, L22.2, U11.22 (RFI_N)
SX1261_RFIP: C73.1, L22.1, U11.21 (RFI_P)
SX1261_RST: R38.1, R60.1, U11.15 (NRESET), U12.18 (PA8)
SX1302_GPIO8: U1.53 (GPIO8), U12.26 (PB3)
TX_ON: R30.1, U1.63 (GPIO2)
TX_RX_SW: R16.2, U1.12 (RADIO_CTRL2)
VCCIO: C3.2, C19.2, C20.2, C25.2, C28.2, C41.2, C42.2, C45.2, C47.2, C76.2, C80.2, C83.2, C86.2, C87.2, C88.2, C89.2, C90.2, Q8.3 (D), R33.1, R34.2, R56.1, R58.1, R65.1, R68.1, R71.1, R80.2, TP1.T, U1.14 (VCC_IO), U1.30 (VCC_IO), U1.47 (VCC_IO), U1.61 (VCC_IO), U12.1 (VDD), U12.5 (VDDA), U12.17 (VDD), U13.3 (VDD)
VCC_1V2: C12.2, C13.2, C23.2, C24.2, C29.2, C40.2, C43.2, C44.2, C71.2, C72.2, L5.2, R79.1, R83.2, TP14.T, U1.5 (VCC_CORE), U1.23 (VCC_CORE), U1.40 (VCC_CORE), U1.56 (VCC_CORE), U6.5 (OUT)
VCC_FEM: C26.2, C27.2, C49.2, C50.2, C51.2, C55.2, FB1.2, L2.2, R2.2, TP6.T, U3.5 (VOUT)
VCC_RADIO: C21.2, C32.2, C33.2, C35.2, C39.2, C48.2, C67.1, L4.2, L7.1, L15.1, R7.2, R36.1, R38.2, R42.2, TP10.T, U4.5 (VOUT), U5.2 (VDD_IN), U5.9 (VBAT_RF), U5.10 (VBAT_DIO), U7.2 (VDD_IN), U7.9 (VBAT_RF), U7.10 (VBAT_DIO), U11.10 (VBAT), U11.11 (VBAT_IO)
VIN: C15.2, C22.2, C30.2, C31.2, C69.2, C70.2, J1.2 (3V3), J1.24 (3V3), J1.39 (3V3), J1.41 (3V3), J1.52 (3V3), Q8.2 (S), R2.1, R7.1, R8.2, R47.1, R78.1, R82.1, TP4.T, U3.1 (VIN), U4.1 (VIN), U6.2 (VIN)

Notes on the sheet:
V1.0
Initial Release
2020/01/02
Vincent
50ohm Impedence
3.3V
300mA
1.2V
500mA
100mA
USB
868
915
SPI
For Power-up delay
V1.1
Add power up delay circuit at VCCIO
Add power up reset circuit for SX1302
Change pins refer to Semtech V3 Schematic
2021/02/18



Board: 4 copper layers, 30.0 x 51.0 mm, 244 parts (68 on the bottom side), 162 nets.

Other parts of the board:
U$45: SEEED-SILK-TNAME-280*268MIL

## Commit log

2025-05-02 add obsidian one
    [Grove - Vision AI Module V2.kicad_pcb, Grove - Vision AI Module V2.kicad_sch, Grove_Vision_AI_V2_BOM.xlsx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]
2025-05-02 change directory name
    [Grove - Vision AI Module V2.kicad_pcb, Grove - Vision AI Module V2.kicad_sch, Grove_Vision_AI_V2_BOM.xlsx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]
2025-05-03 add KMK firmware + install instructions
    [bom.csv, designators.csv, positions.csv]
2025-06-05 add stuff
    [case.stl]
2025-10-25 Update source links in bom.csv
    Updated source links for Kailh Hotswap Sockets and 1N4148 THT Diodes.
    [bom.csv]
